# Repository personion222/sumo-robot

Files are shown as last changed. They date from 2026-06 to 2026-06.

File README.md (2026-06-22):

# sumo-robot
**Speedbump** - TEJ3MI sumo robot competition 2nd place winner.
- designed in OnShape and 3D printed
    <details>
    <summary>3D model screenshots</summary>

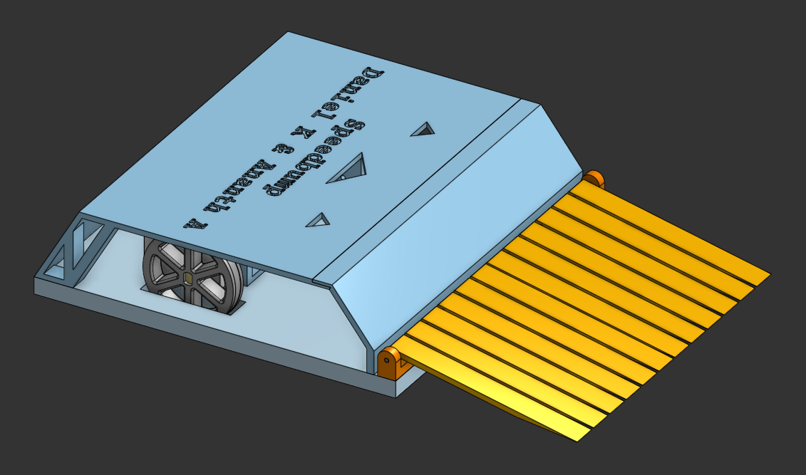
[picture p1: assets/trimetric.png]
trimetric view
    
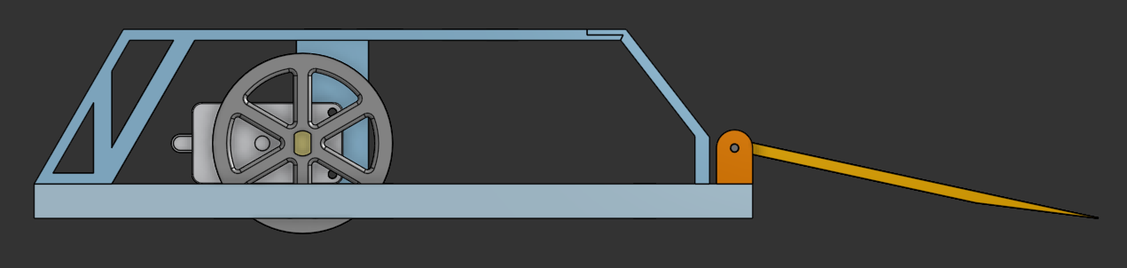
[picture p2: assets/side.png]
side view
    
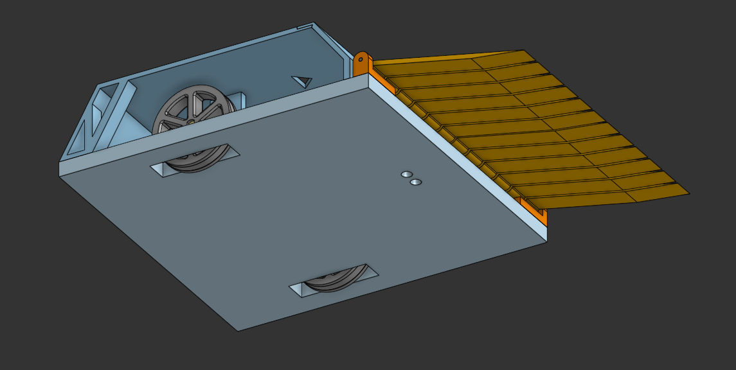
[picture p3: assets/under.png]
under view
    
    </details><br>
- board designed in KiCad
    <details>
    <summary>schematic screenshots</summary>
    
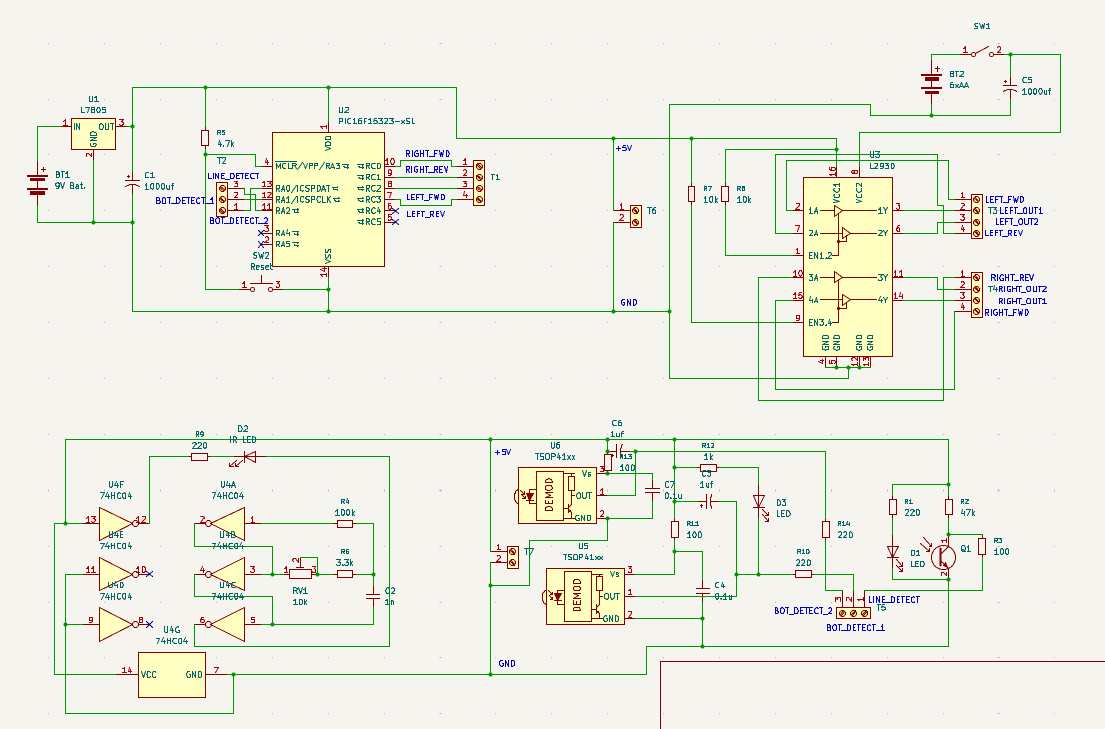
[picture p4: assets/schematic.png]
schematic
    
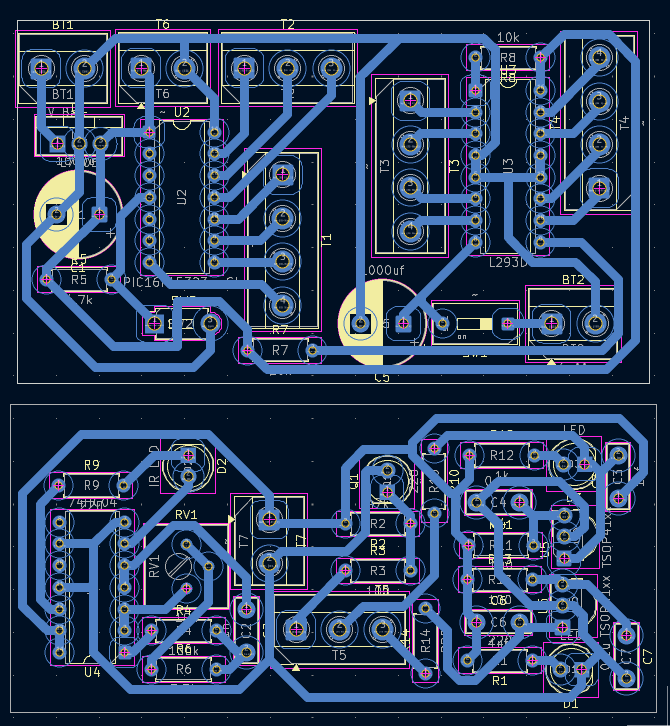
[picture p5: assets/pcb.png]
pcb
    
    </details><br>
- powered by PIC16F15323 programmed with GCBasic script

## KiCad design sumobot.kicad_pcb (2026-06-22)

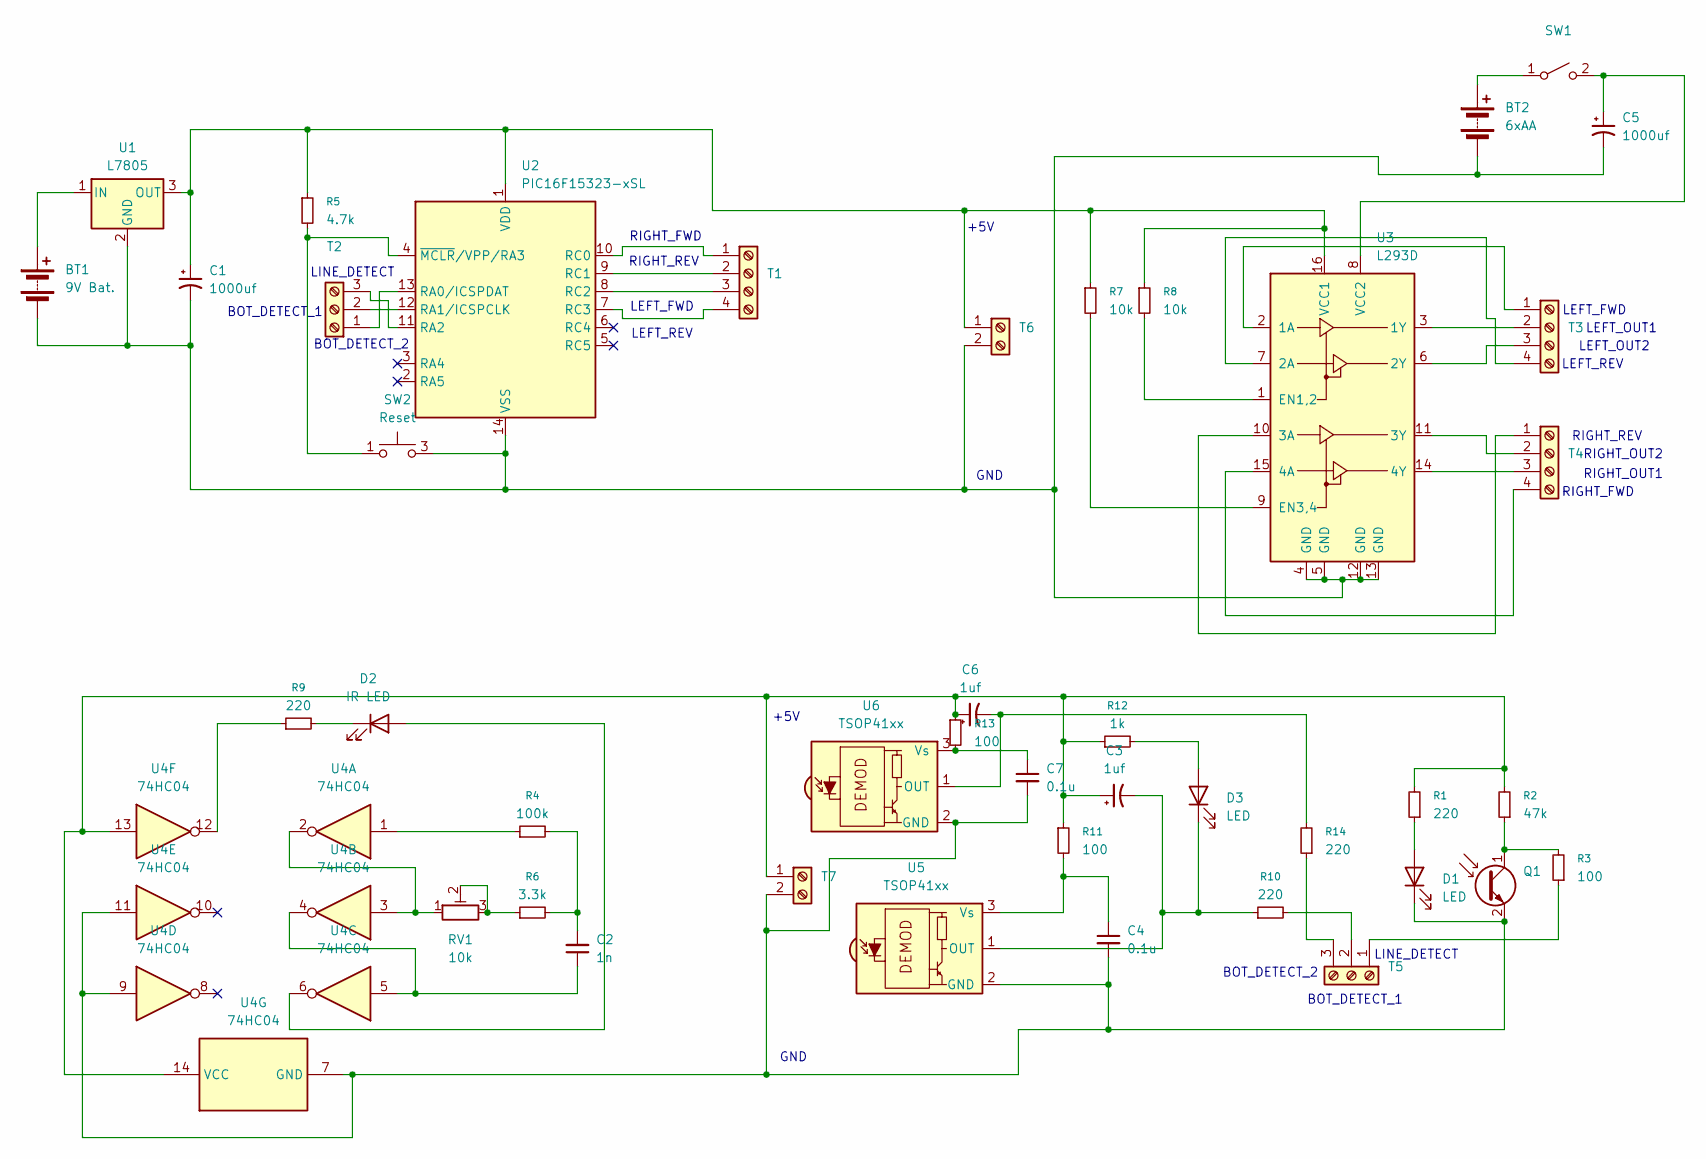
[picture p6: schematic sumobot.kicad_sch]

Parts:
BT1: 9V Bat.; TerminalBlock_MetzConnect_Type101_RT01602HBWC_1x02_P5.08mm_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
BT2: 6xAA; TerminalBlock_MetzConnect_Type101_RT01602HBWC_1x02_P5.08mm_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
C1, C5: 1000uf; CP_Radial_D10.0mm_P5.00mm
C2: 1n; C_Disc_D7.5mm_W2.5mm_P5.00mm
C3, C6: 1uf; C_Disc_D7.5mm_W2.5mm_P5.00mm
C4, C7: 0.1u; C_Disc_D7.5mm_W2.5mm_P5.00mm
D1, D3: LED; LED_D5.0mm_Clear
D2: IR LED; LED_D5.0mm_IRBlack
Q1: LED_D5.0mm_Clear
R1, R9, R10, R14: 220; R_Axial_DIN0207_L6.3mm_D2.5mm_P7.62mm_Horizontal
R2: 47k; R_Axial_DIN0207_L6.3mm_D2.5mm_P7.62mm_Horizontal
R3, R11, R13: 100; R_Axial_DIN0207_L6.3mm_D2.5mm_P7.62mm_Horizontal
R4: 100k; R_Axial_DIN0207_L6.3mm_D2.5mm_P7.62mm_Horizontal
R5: 4.7k; R_Axial_DIN0207_L6.3mm_D2.5mm_P7.62mm_Horizontal
R6: 3.3k; R_Axial_DIN0207_L6.3mm_D2.5mm_P7.62mm_Horizontal
R7, R8: 10k; R_Axial_DIN0207_L6.3mm_D2.5mm_P7.62mm_Horizontal
R12: 1k; R_Axial_DIN0207_L6.3mm_D2.5mm_P7.62mm_Horizontal
RV1: 10k; Potentiometer_Bourns_3386P_Vertical
SW1: SW_DIP_SPSTx01_Slide_9.78x4.72mm_W7.62mm_P2.54mm
SW2: Reset; SW_PUSH_1P1T_6x3.5mm_H5.0_APEM_MJTP1250
T1, T3, T4: TerminalBlock_MetzConnect_Type101_RT01604HBWC_1x04_P5.08mm_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
T2, T5: TerminalBlock_MetzConnect_Type101_RT01603HBWC_1x03_P5.08mm_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
T6, T7: TerminalBlock_MetzConnect_Type101_RT01602HBWC_1x02_P5.08mm_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
U1: L7805; TO-220-3_Vertical
U2: PIC16F15323-xSL; DIP-14_W7.62mm
U3: L293D; DIP-16_W7.62mm
U4: 74HC04; DIP-14_W7.62mm
U5, U6: TSOP41xx; Vishay_MOLD-3Pin

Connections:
unnamed: BT1.1 (+), U1.1 (IN)
unnamed: BT1.2 (-), BT2.2 (-), C1.2, C5.2, SW2.3 (B), SW2.4 (B), T6.2, U1.2 (GND), U2.14 (VSS), U3.4 (GND), U3.5 (GND), U3.12 (GND), U3.13 (GND)
unnamed: BT2.1 (+), SW1.1 (A)
unnamed: C2.1, U4.4, U4.5
unnamed: C2.2, R4.2, R6.2
unnamed: D1.2 (A), R1.1
unnamed: C4.2, C7.2, D1.1 (K), Q1.2 (E), T7.2, U4.7 (GND), U4.9, U4.11, U5.2 (GND), U6.2 (GND)
unnamed: D2.2 (A), U4.6
unnamed: D2.1 (K), R9.2
unnamed: D3.2 (A), R12.2
unnamed: C3.2, D3.1 (K), R10.1, U5.1 (OUT)
unnamed: Q1.1 (C), R2.1, R3.2
unnamed: R4.1, U4.1
unnamed: R6.1, RV1.2, RV1.3
unnamed: R9.1, U4.12
unnamed: RV1.1, U4.2, U4.3
unnamed: C5.1, SW1.2 (B), U3.8 (VCC2)
unnamed: T1.1, U2.10 (RC0)
unnamed: T1.2, U2.9 (RC1)
unnamed: T1.3, U2.8 (RC2)
unnamed: T1.4, U2.7 (RC3)
unnamed: T2.1, U2.13 (RA0/ICSPDAT)
unnamed: T2.2, U2.12 (RA1/ICSPCLK)
unnamed: T2.3, U2.11 (RA2)
unnamed: T3.1, U3.2 (1A)
unnamed: T3.2, U3.3 (1Y)
unnamed: T3.3, U3.6 (2Y)
unnamed: T3.4, U3.7 (2A)
unnamed: T4.1, U3.10 (3A)
unnamed: T4.2, U3.11 (3Y)
unnamed: T4.3, U3.14 (4Y)
unnamed: T4.4, U3.15 (4A)
unnamed: R3.1, T5.1
unnamed: R10.2, T5.2
unnamed: R14.1, T5.3
unnamed: C1.1, R5.1, R7.1, R8.1, T6.1, U1.3 (OUT), U2.1 (VDD), U3.16 (VCC1)
unnamed: C3.1, C6.1, R1.2, R2.2, R11.1, R12.1, R13.1, T7.1, U4.13, U4.14 (VCC)
unnamed: R5.2, SW2.1 (A), SW2.2 (A), U2.4 (~MCLR/VPP/RA3)
unnamed: R8.2, U3.1 (EN1,2)
unnamed: R7.2, U3.9 (EN3,4)
unnamed: C4.1, R11.2, U5.3 (Vs)
unnamed: C6.2, R14.2, U6.1 (OUT)
unnamed: C7.1, R13.2, U6.3 (Vs)

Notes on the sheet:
LINE_DETECT
BOT_DETECT_2
BOT_DETECT_1
RIGHT_REV
LEFT_FWD
LEFT_REV
LEFT_OUT1
RIGHT_FWD
GND
LEFT_OUT2
+5V
RIGHT_OUT2
RIGHT_OUT1
BOT_DETECT_2
BOT_DETECT_1

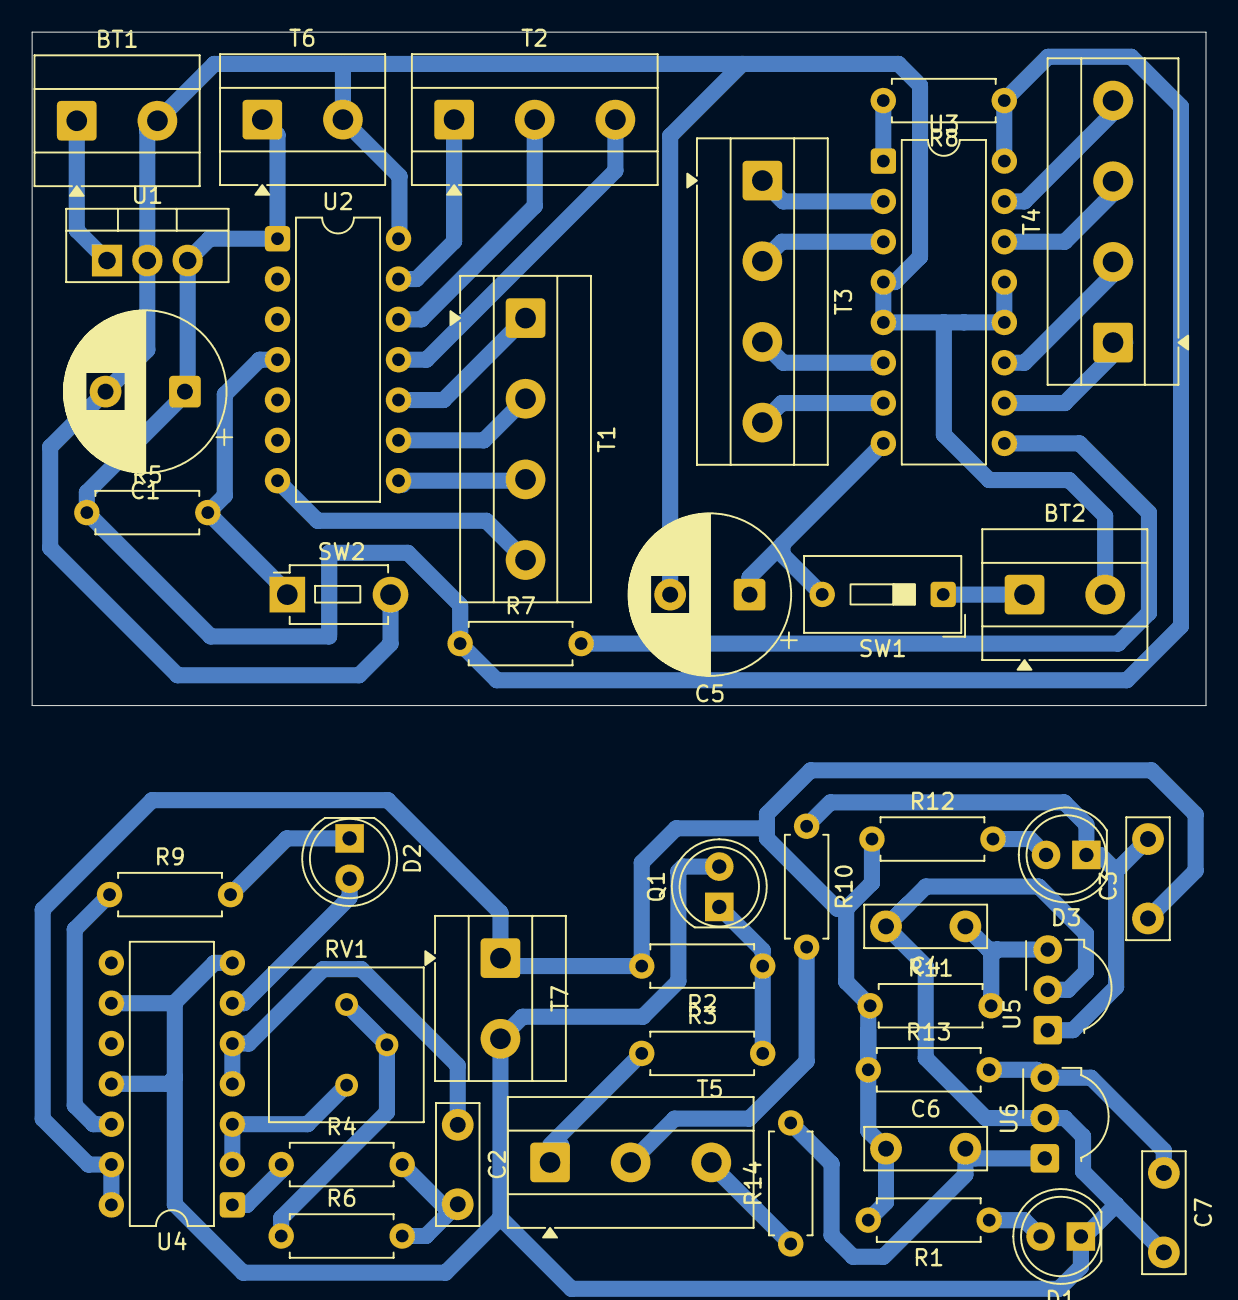
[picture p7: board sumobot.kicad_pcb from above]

Board: 2 copper layers, 73.9 x 42.4 mm, 43 parts (0 on the bottom side), 43 nets.
